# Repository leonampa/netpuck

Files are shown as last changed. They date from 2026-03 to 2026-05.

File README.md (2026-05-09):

# **NetPuck 5G: A Specialized 5GHz Wireless & Network Auditor**

----------

# 🗃️ This project has been archived.
**9th May:** It’s been 30 days since my latest ticket to Support, and over five weeks since the last human feedback. At this point, the project has shifted from a fun hardware challenge into a lingering chore on my to-do list. The educational ROI has hit its limit - I’ve already learned what I came for: Fusion 360, KiCad, etc. Since the program has stalled on the administrative side, I’m officially archiving the NetPuck to clear my headspace for projects that actually move forward. 

----------

# **0\. Introduction**

The NetPuck 5G is a handheld device, purpose-built to connect the worlds of software-driven network diagnostics and hardware-focused wireless analysis.

Made on Hack Club Blueprint 🚩- [https://blueprint.hackclub.com/projects/13740](https://blueprint.hackclub.com/projects/13740)

## **0.1 Why did I build this?**

* **I needed a network auditing device.** As a beginner IT Support Technician, I have a vast variety of tools for every job, but I've been lacking tools (and knowledge) regarding networking infrastructure. I've been making do with my phone and generic, no-brand WiFi strength scanning applications on my phone, but that is just not reliable for my purpose.  
* **I wanted to learn about hardware engineering.** I've always been interested in the “guts” of the devices around me. From a very young age, with a screwdriver in hand, I started taking devices that would otherwise be trashed apart, curious to see what makes them work. A few months ago, I also bought a soldering iron, and learned the skill of soldering and desoldering. In my curious journey of hardware engineering, the next step would be designing and having a custom PCB made.  
* **I wanted something to showcase in my portfolio.** Projects and contributions are largely important factors in one's portfolio, especially at an age where they cannot work, like me. I wanted to enrich my portfolio with personal projects, and Hack Club’s blueprint was the perfect, guided opportunity for me to do so.

## **0.2 What is it made of?**

It uses:

* the Waveshare ESP32-S3 Pico, as the main processing unit for the entire device  
* a BW16, solely for Access Point scanning, thanks to its 5GHz capabilities   
* a W5500 Ethernet module, for listing details about the network it is connected to  
* a 1.8’ inch LCD module, for providing all information gathered from the aforementioned boards to the user  
* a low-profile 5-way digital navigation joystick, for navigating the menus of the device  
* a MH-CD42 charging and boost-up module and two Samsung 18650 batteries, for powering the device from batteries, reliably.

## **0.3 So, what does it do?**

The NetPuck 5G has two functions; Wireless Access Point strength scanning, and Wired Network details.

* Wireless Access Point strength scanning  
  * This function uses the BW16, which communicates with the ESP32 via UART to list all 2.4GHz and 5GHz Access Points within reach, and the strength of each one, measured in dBm.  
* LAN details  
  * This function detects specific details about the network the W5500 module is plugged into. Specifically: ICMP Echo to 8.8.8.8, Gateway IP (from DHCP Lease), ICMP Echo to Gateway (Confirms local LAN integrity), LLDP (Passive sniff for Link Layer Discovery Protocol packets), Reverse DNS lookup of the Gateway’s Public IP, Gateway Domain Name (from DHCP Option 15), NLA Information, Gateway MAC (ARP-resolved)

# **1\. Pinout**

Grounds not listed; all grounds connect to each other  
The Pin/As/To/For tables are read as: The Pin \[Pin\] functions as/is labeled as \[As\], and goes to pin \[To\], (and is used) for \[For\].   

## **1.1 ESP32-S3**

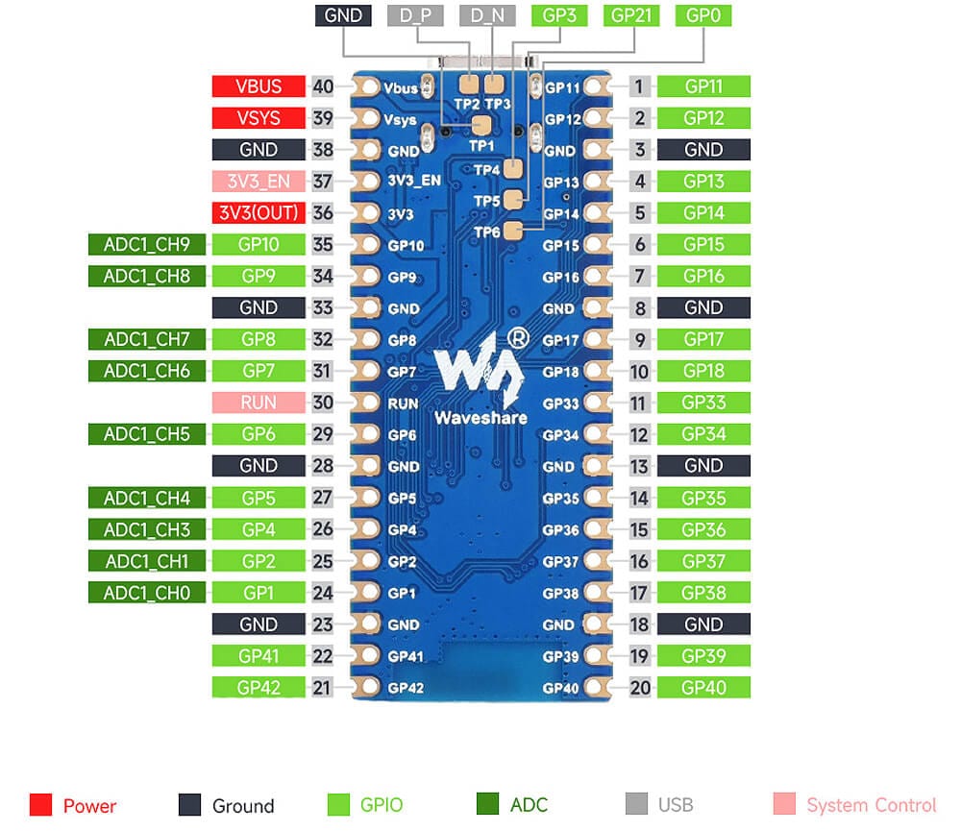
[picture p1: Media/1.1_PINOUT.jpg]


| Pin | As | To | For |
| :---- | :---- | :---- | :---- |
| Vbus/40 | \+5V | MH-CD42 @ 5V OUT | Powering the ESP |
| GP5/27 | LCD\_BL | LCD @ BL | Controlling the backlight |
| GP6/29 | W5500\_RST | W5500 @ RST | Resetting the W5500 |
| GP7/31 | LCD\_RST | LCD @ RST | LCD’s Resetting the LCD |
| GP8/32 | LCD\_DC | LCD @ DC | Data/Command |
| GP9/33 | W5500\_CS | W5500 @ CS | W5500’s SPI Chip Select  |
| GP10/34 | LCD\_CS | LCD @ CS | LCD’s SPI Chip Select |
| 3V3/36 | 3V3 | LCD @ VCC, W5500 @ V | Powering the LCD and W5500 |
| GP11/1 | SPI\_MOSI | LCD @ DIN, W5500 @ MO | Transferring data via SPI from the ESP32 (Master), to the LCD and W5500 (Slaves) |
| GP12/2 | SPI\_SCK | LCD @ CLK, W5500 @ SCK | Serial Clock for SPI |
| GP13/4 | SPI\_MISO | W5500 @ MI | Transferring data via SPI from the W5500 (Slave) to the ESP32 (Master) |
| GP14/5 | BW16\_EN | BW16 @ EN | BW16’s Enable Pin |
| GP17/9 | BW16\_RX | BW16 @ 7 | UART (ESP32 → BW16) |
| GP18/10 | BW16\_TX | BW16 @ 8 | UART (ESP32 ← BW16) |
| GP34/12 | MID | STICK @ MID | Joystick’s Click |
| GP35/14 | UP | STICK @ UP | Joystick’s Up |
| GP36/15 | DOWN | STICK @ DOWN | Joystick’s Down |
| GP37/16 | LEFT | STICK @ LEFT | Joystick’s Left |
| GP38/17 | RIGHT | STICK @ RIGHT | Joystick’s Right |

## **1.2 BW16**

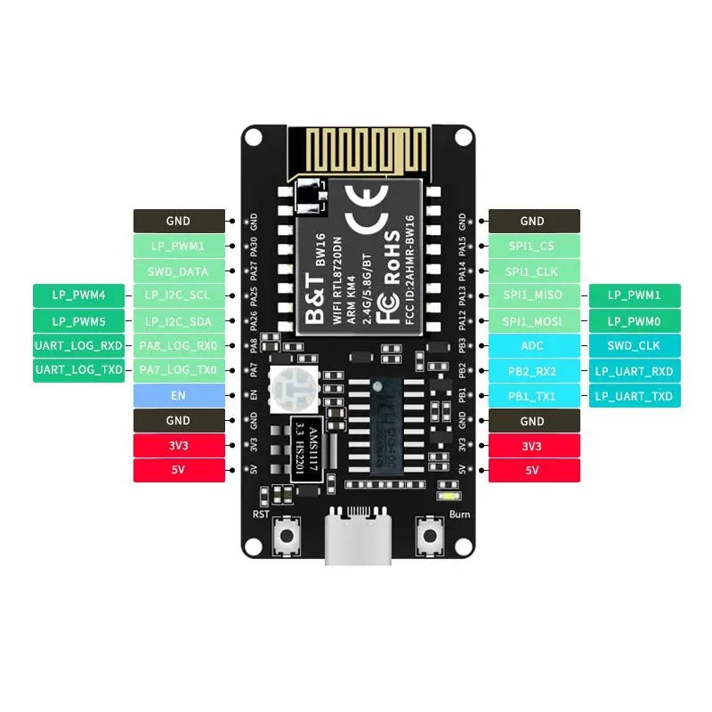
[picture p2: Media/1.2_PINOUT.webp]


| Pin | As | To | For |
| :---- | :---- | :---- | :---- |
| 5V | \+5V | MH-CD42 @ 5V OUT | Powering the BW16 |
| PA7/TX | BW16\_TX | ESP @ GP17/9 | UART (ESP32 ← BW16) |
| PA8/RX | BW16\_RX | ESP @ GP18/10 | UART (ESP32 → BW16) |
| EN | BW16\_EN | ESP @ GP14/5 | Enable Pin |

## **1.3 W5500**

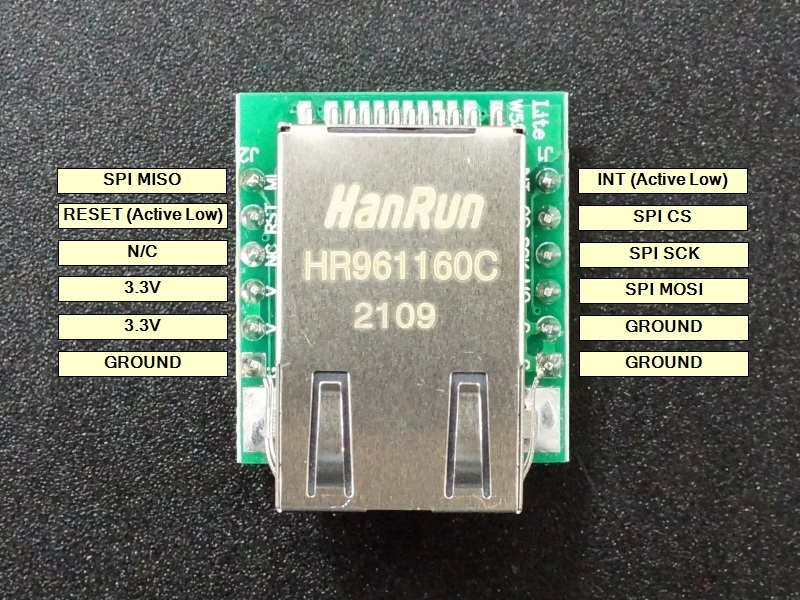
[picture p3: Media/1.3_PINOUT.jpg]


| Pin | As | To | For |
| :---- | :---- | :---- | :---- |
| RST | W5500\_RST | ESP @ GP6/29 | Resetting the W5500 |
| CS | W5500\_CS | ESP @ GP9/34 | W5500’s SPI Chip Select  |
| V | 3V3 | ESP @ 3V3 | Powering the LCD and W5500 |
| SCK | SPI\_SCK | ESP @ GP12/2 | Serial Clock for SPI |
| MI | SPI\_MISO | ESP @ GP13/4 | Transferring data via SPI from the W5500 (Slave) to the ESP32 (Master) |
| MO | SPI\_MOSI | ESP @ GP11/1 | Transferring data via SPI from the ESP32 (Master), to theW5500 (Slave) |

## **1.4 LCD**

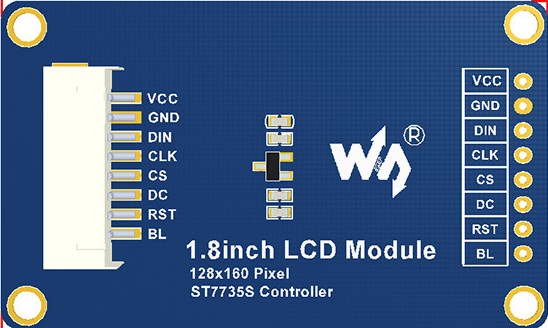
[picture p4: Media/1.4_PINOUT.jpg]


| Pin | As | To | For |
| :---- | :---- | :---- | :---- |
| BL  | LCD\_BL | ESP @ GP5/27 | Controlling the backlight |
| RST  | LCD\_RST | ESP @ GP7/31 | Resetting the LCD |
| DC  | LCD\_DC | ESP @ GP8/32 | LCD’s Data/Command |
| CS  | LCD\_CS | ESP @ GP10/34 | LCD’s SPI Chip Select |
| VCC  | 3V3 | ESP @ 3V3/36 | Powering the LCD |
| DIN  | SPI\_MOSI | ESP @ GP11/1 | Transferring data via SPI from the ESP32 (Master), to the LCD (Slave) |
| CLK  | SPI\_SCK | ESP @ GP12/2 | Serial Clock for SPI |

## **1.5 Joystick** 

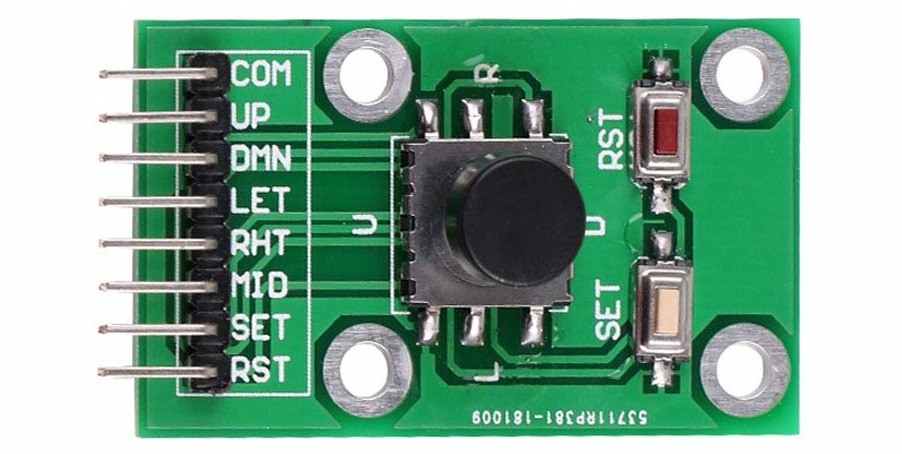
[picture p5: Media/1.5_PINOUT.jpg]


| Pin | As | To | For |
| :---- | :---- | :---- | :---- |
| MID | MID | ESP @ GP34/12 | Joystick’s Click |
| UP | UP | ESP @ GP35/14 | Joystick’s Up |
| DOWN | DOWN | ESP @ GP36/15 | Joystick’s Down |
| LEFT | LEFT | ESP @ GP37/16 | Joystick’s Left |
| RIGHT | RIGHT | ESP @ GP38/17 | Joystick’s Right |

## **1.6 MH-CD42 Charging Module**

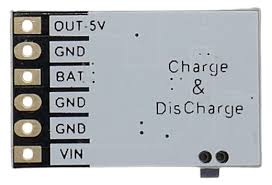
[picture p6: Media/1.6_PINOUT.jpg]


| Pin | As | To | For |
| :---- | :---- | :---- | :---- |
| 5V OUT | \+5V | ESP @ Vbus/40, BW16 @ 5V | Powering the ESP and BW16 |
| VIN  | VUSB | USB @ V | Powering the MH-CD42 |
| BAT | VBAT | (external batteries) | Powering the MH-CD42 |

## **1.7 USB Port**

| Pin | As | To | For |
| :---- | :---- | :---- | :---- |
| V | VUSB | VIN | Powering the MH-CD42 |

# **2\. PCB**

I used KiCad to design the PCB. Through a few struggles (as described on Journal), I landed on this design:

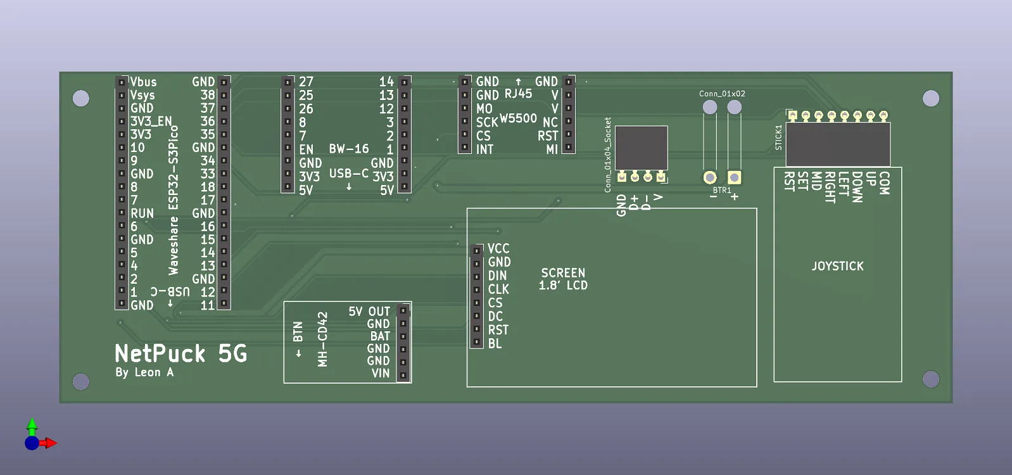
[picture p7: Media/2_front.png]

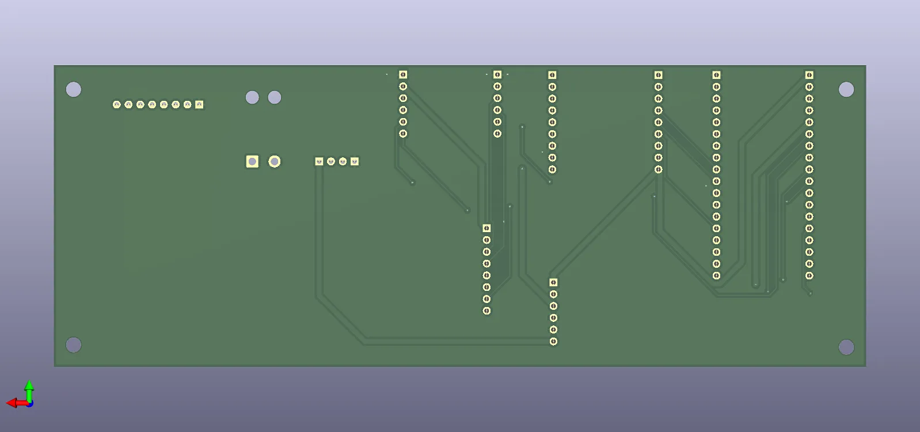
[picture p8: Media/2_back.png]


# **3\. Case**

I used Autodesk Fusion to make the case (as described on Journal). The enclosure is designed for field durability, featuring a 'Sandwich Mount' architecture. It utilizes M3 heat-set inserts and M3 Nylon screws, instead of Stainless Steel, to avoid signal interference.

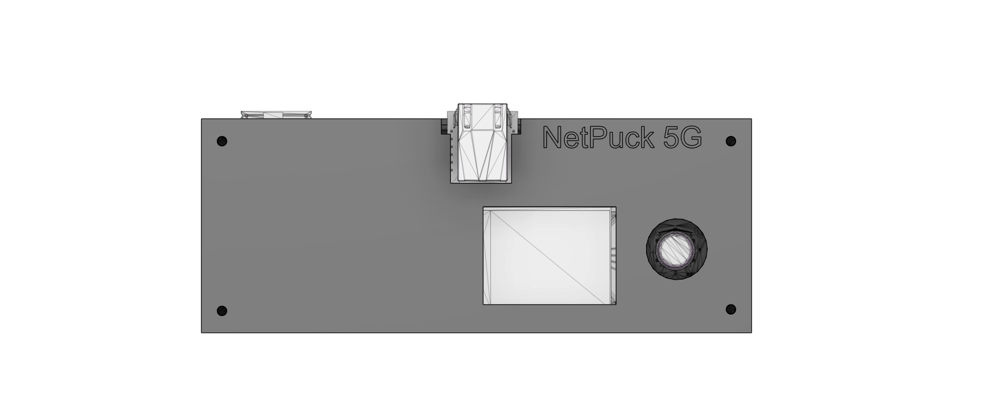
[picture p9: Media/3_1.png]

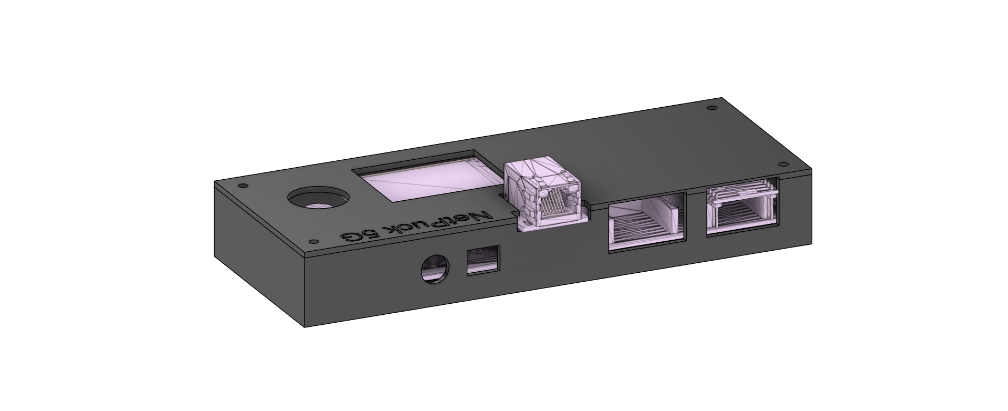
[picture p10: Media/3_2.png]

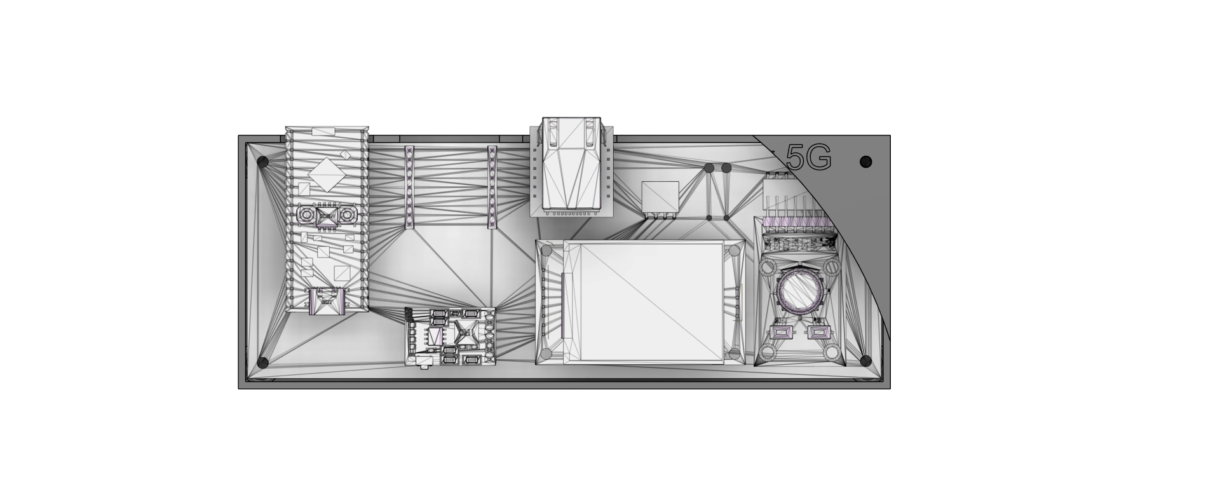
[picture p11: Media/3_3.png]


# **4\. Bill Of Materials**

| Item | €/pcs | Qty | € Total | Link |
| :---- | ----- | ----- | ----- | :---- |
| **GRobotronics** |  |  |  |  |
| eSUN PETG+HS 1.75mm 1kg \- Solid Black | €19.90 | 1 | €19.90 | [https://grobotronics.com/esun-petghs-1-75mm-1kg-solid-black.html](https://grobotronics.com/esun-petghs-1-75mm-1kg-solid-black.html) |
| Soldering Wire Brofil 60 100g 1mm | €7.20 | 1 | €7.20 | [https://grobotronics.com/soldering-wire-brofil-60-100g-1mm.html](https://grobotronics.com/soldering-wire-brofil-60-100g-1mm.html) |
| Waveshare ESP32-S3 Pico With Pre-soldered Headers | €13.60 | 1 | €13.60 | [https://grobotronics.com/waveshare-esp32-s3-development-board.html?variation\_id=18355](https://grobotronics.com/waveshare-esp32-s3-development-board.html?variation_id=18355) |
| Battery Lithium 18650 3.6V 3400mAh \- Samsung INR18650-35E | €5.80 | 2 | €11.60 | [https://grobotronics.com/battery-lithium-18650-3.6v-3400mah-8a-samsung-inr18650-35e.html](https://grobotronics.com/battery-lithium-18650-3.6v-3400mah-8a-samsung-inr18650-35e.html) |
| Battery Holder 2x18650 \- with Wires & Switch | €1.20 | 1 | €1.20 | [https://grobotronics.com/battery-lithium-18650-3.6v-3400mah-8a-samsung-inr18650-35e.html](https://grobotronics.com/battery-lithium-18650-3.6v-3400mah-8a-samsung-inr18650-35e.html) |
| Joystick Module 5-Way | €2.60 | 1 | €2.60 | [https://grobotronics.com/5-way-joystick-module.html](https://grobotronics.com/5-way-joystick-module.html) |
| Waveshare LCD 1.8" 128×160 SPI | €11.20 | 1 | €11.20 | [https://grobotronics.com/display-1.8-128x160-lcd-module.html](https://grobotronics.com/display-1.8-128x160-lcd-module.html) |
| USB Type-C Breakout Board \- Straight Header | €0.80 | 1 | €0.80 | [https://grobotronics.com/usb-type-c-breakout-board-straight-header.html](https://grobotronics.com/usb-type-c-breakout-board-straight-header.html) |
| Pin Header 1x40 Male 2.54 mm Black | €0.10 | 1 | €0.10 | [https://grobotronics.com/pin-header-1x40-male-2.54-mm-black.html](https://grobotronics.com/pin-header-1x40-male-2.54-mm-black.html) |
| Pin Header 1x10 Female 2.54mm | €0.17 | 4 | €0.68 | [https://grobotronics.com/pin-header-1x10-female-2.54mm.html](https://grobotronics.com/pin-header-1x10-female-2.54mm.html) |
| Pin Header 1x8 Female 2.54mm | €0.10 | 3 | €0.30 | [https://grobotronics.com/pin-header-1x8-female-2.54mm.html](https://grobotronics.com/pin-header-1x8-female-2.54mm.html) |
| Arduino Long Header 8pins | €0.25 | 1 | €0.25 | [https://grobotronics.com/arduino-long-header-8pins.html](https://grobotronics.com/arduino-long-header-8pins.html) |
| Pin Header Female 1x6 2.54mm | €0.08 | 3 | €0.24 | [https://grobotronics.com/pin-header-1x6-female-2.54mm.html](https://grobotronics.com/pin-header-1x6-female-2.54mm.html) |
| Pin Header 1x4 Long Stackable | €0.20 | 1 | €0.20 | [https://grobotronics.com/pin-header-1x4-long-stackable.html](https://grobotronics.com/pin-header-1x4-long-stackable.html) |
| Threaded Insert M3 \- 5.7x4.6mm | €0.15 | 10 | €1.50 | [https://grobotronics.com/threaded-insert-m3-short-3x4-6.html](https://grobotronics.com/threaded-insert-m3-short-3x4-6.html) |
| Bolt M3 \- Nylon (20mm) | €0.30 | 10 | €3.00 | [https://grobotronics.com/m3.html?variation\_id=12363](https://grobotronics.com/m3.html?variation_id=12363) |
| High Temperature Adhesive Tape 50mm \- 33m | €7.90 | 1 | €7.90 | [https://grobotronics.com/high-temperature-adhesive-tape-50mm-33m.html](https://grobotronics.com/high-temperature-adhesive-tape-50mm-33m.html) |
| YATO YT-2081 Side Cutting Pliers 115mm | €3.60 | 1 | €3.60 | [https://grobotronics.com/yato-cutting-pliers-115mm.html](https://grobotronics.com/yato-cutting-pliers-115mm.html) |
| Shipping (BOXNOW) | €0.00 | 0 | €0.00 |  |
| **Subtotal** |  | 44 | €85.87 |  |
|  |  |  |  |  |
| **AliExpress** |  |  |  |  |
| Dual-band WiFi \+ Bluetooth 5.0 IoT Core Board (BW16 RTL8720DN) Suitable for Arduino and Smart Home Projects (IPEX Antenna) | €7.24 | 1 | €9.52 | [https://www.aliexpress.com/item/1005010064459718.html?spm=a2g0o.detail.0.0.7236U0QJU0QJSg\&mp=1\&pdp\_npi=6%40dis%21EUR%21EUR%209.55%21EUR%201.95%21%21EUR%201.95%21%21%21%402103835e17741877141951141e5be7%2112000051007214201%21ct%21GR%21-1%21%211%210%21](https://www.aliexpress.com/item/1005010064459718.html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) |
| 1PCS W5500 Module TCP/IP Ethernet Module Compatible with WIZ820io Network Interface RC5 IoT for Arduino | €3.91 | 1 | €4.54 | [https://www.aliexpress.com/item/1005004679288698.html?spm=a2g0o.detail.0.0.7236U0QJU0QJSg\&mp=1\&pdp\_npi=6%40dis%21EUR%21EUR%204.54%21EUR%200.88%21%21EUR%200.88%21%21%21%402103835e17741877141951141e5be7%2112000030074096066%21ct%21GR%21-1%21%211%210%21](https://www.aliexpress.com/item/1005004679288698.html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) |
| 5/10pcs DC 5V 2A Mobile Power Diy Board 4.2V Charge/Discharge(boost)/battery protection/indicator module 3.7V lithium 18650 (MH-CD42) | €2.71 | 1 | €3.13 | [https://www.aliexpress.com/item/1005007432099008.html?spm=a2g0o.productlist.main.1.6d655d0d201MlN\&algo\_pvid=0b38d990-1f78-4ed4-ab89-ce53223c6fe6\&algo\_exp\_id=0b38d990-1f78-4ed4-ab89-ce53223c6fe6-8\&pdp\_ext\_f=%7B%22order%22%3A%22861%22%2C%22eval%22%3A%221%22%2C%22fromPage%22%3A%22search%22%7D\&pdp\_npi=6%40dis%21EUR%213.13%212.71%21%21%213.53%213.06%21%4021039a5b17741899750876391e3fa0%2112000040730748938%21sea%21GR%216308147579%21X%211%210%21n\_tag%3A-29919%3Bd%3A73d1907e%3Bm03\_new\_user%3A-29895%3BpisId%3A5000000202472607\&curPageLogUid=w2UUTZk6Qdsr\&utparam-url=scene%3Asearch%7Cquery\_from%3A%7Cx\_object\_id%3A1005007432099008%7C\_p\_origin\_prod%3A](https://www.aliexpress.com/item/1005007432099008.html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) |
| Shipping (AliExpress Choice) | €0.00 | 0 | €0.00 |  |
| **Subtotal** |  | 3 | €17.19 |  |
|  |  |  |  |  |
| **JLCPCB** |  |  |  |  |
| PCB (2 layers) | €7.43 | 1 | €7.43 |  |
| Shipping (Global Standard Direct Line) | €7.75 | 1 | €7.75 |  |
| New User Discount | \-€5.19 | 1 | \-€5.19 |  |
|  |  |  | €9.99 |  |
|  |  |  |  |  |
| **TOTAL** |  |  | €113.05 |  |
| **Conversion to USD (rate from Google Finance, €1 \=** | $1.154 |  | $130.49 |  |

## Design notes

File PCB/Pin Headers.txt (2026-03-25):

Pin Headers
ESP32: 2*10pF, 2*8pF
BW16: 2*10pF
MH-CD42: 1*6pF, 1*6pM
W5500: 2*6pF
Screen: 1*8pF, 1*8pM
USB: 1*4pFAR
Joystick: 1*8pFAL

Total
4*10pF
3*8pF, 1*8pM, 1*8pFAL
3*6pF, 1*6pM
1*4pFAR
=14

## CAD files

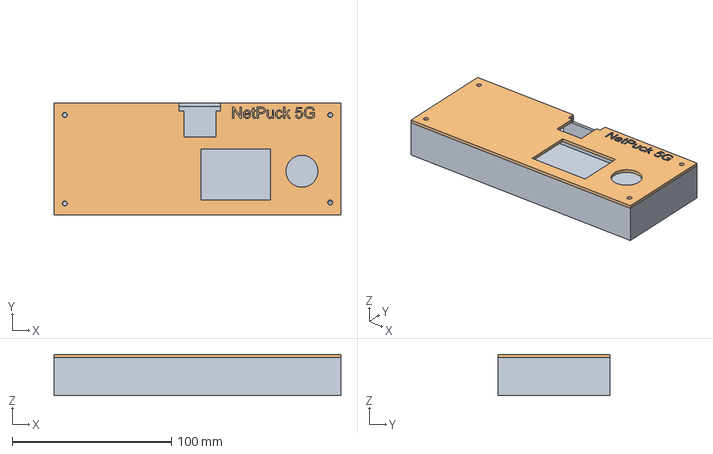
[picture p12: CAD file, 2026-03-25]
Case/NetPuck5G (case without PCB).step
180.0 x 70.0 x 26.0 mm

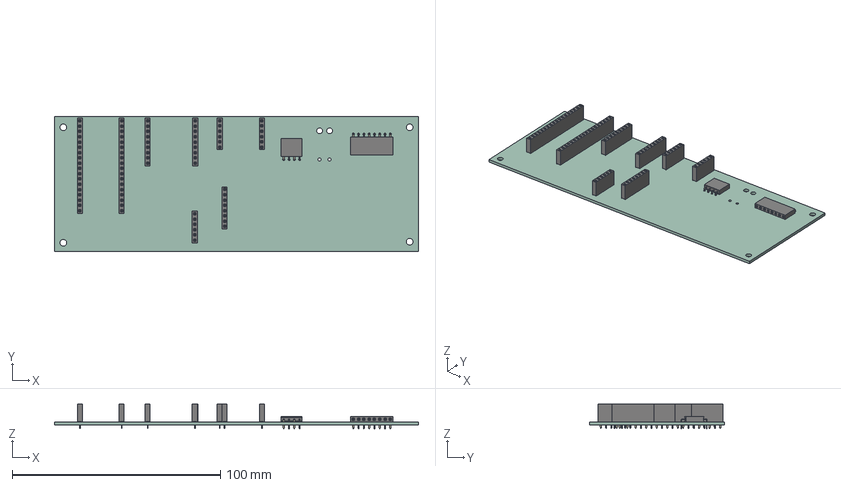
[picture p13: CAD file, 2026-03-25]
PCB/NetPuck5G.step
175.0 x 65.0 x 11.8 mm
PinSocket_1x06_P2.54mm_Vertical x 3
PinSocket_1x09_P2.54mm_Vertical x 2
PinSocket_1x18_P2.54mm_Vertical x 2
PinSocket_1x08_P2.54mm_Horizontal
PinSocket_1x08_P2.54mm_Vertical
PinSocket_1x04_P2.54mm_Horizontal
NetPuck5G_PCB

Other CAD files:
Case/NetPuck5G (case with PCB).step
Case/NetPuck5G (case with PCB).f3d
Case/NetPuck5G (case without PCB).f3d

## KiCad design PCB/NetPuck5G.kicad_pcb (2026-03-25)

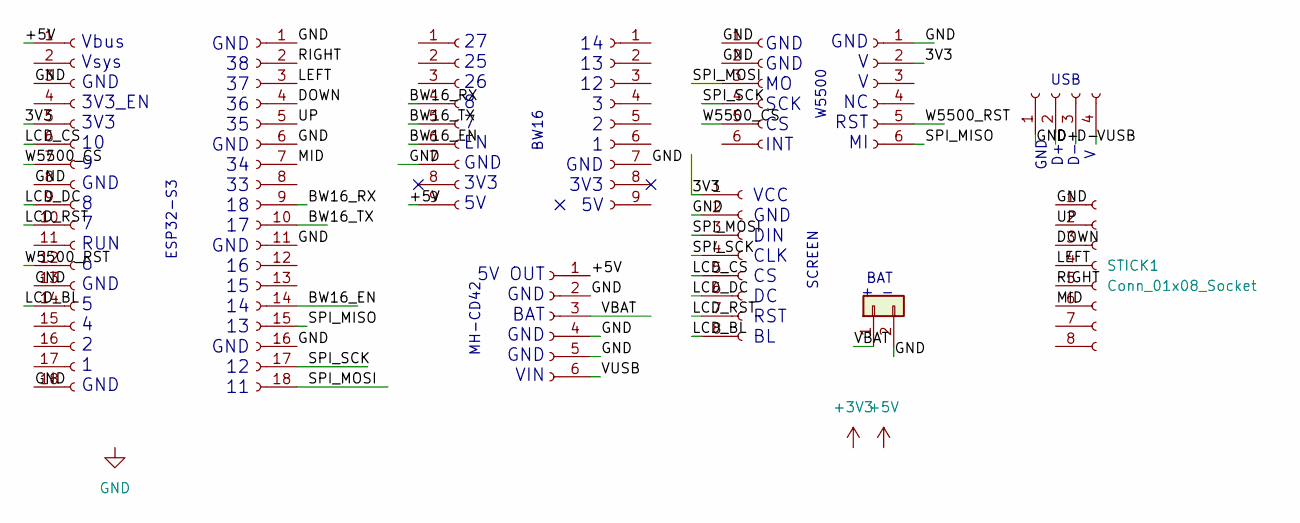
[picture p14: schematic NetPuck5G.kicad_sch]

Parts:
BTR1: Conn_01x02
BW-16_L1, BW-16_R1: Conn_01x09_Socket
ESP_L1: ESP_L
ESP_R1: Conn_01x18_Socket
ETH_L1: Conn_01x06_Socket
ETH_R1: Conn_01x06_Socket
MH-CD42: Conn_01x06_Socket
SCR1: Conn_01x08_Socket
STICK1: Conn_01x08_Socket
USB1: Conn_01x04_Socket

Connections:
+5V: BW-16_L1.9, ESP_L1.1, MH-CD42.1
/3V3: ESP_L1.5, ETH_R1.2, SCR1.1
/BW16_EN: BW-16_L1.6, ESP_R1.14
/BW16_RX: BW-16_L1.4, ESP_R1.9
/BW16_TX: BW-16_L1.5, ESP_R1.10
/D+: USB1.2
/D-: USB1.3
/DOWN: ESP_R1.4, STICK1.3
/LCD_BL: ESP_L1.14, SCR1.8
/LCD_CS: ESP_L1.6, SCR1.5
/LCD_DC: ESP_L1.9, SCR1.6
/LCD_RST: ESP_L1.10, SCR1.7
/LEFT: ESP_R1.3, STICK1.4
/MID: ESP_R1.7, STICK1.6
/RIGHT: ESP_R1.2, STICK1.5
/SPI_MISO: ESP_R1.15, ETH_R1.6
/SPI_MOSI: ESP_R1.18, ETH_L1.3, SCR1.3
/SPI_SCK: ESP_R1.17, ETH_L1.4, SCR1.4
/UP: ESP_R1.5, STICK1.2
/VBAT: BTR1.1, MH-CD42.3
/VUSB: MH-CD42.6, USB1.4
/W5500_CS: ESP_L1.7, ETH_L1.5
/W5500_RST: ESP_L1.12, ETH_R1.5
GND: BTR1.2, BW-16_L1.7, BW-16_R1.7, ESP_L1.3, ESP_L1.8, ESP_L1.13, ESP_L1.18, ESP_R1.1, ESP_R1.6, ESP_R1.11, ESP_R1.16, ETH_L1.1, ETH_L1.2, ETH_R1.1, MH-CD42.2, MH-CD42.4, MH-CD42.5, SCR1.2, STICK1.1, USB1.1

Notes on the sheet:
BAT
GND 38 37 36 35 GND 34 33 18 17 GND 16 15 14 13 GND 12 11
GND V V NC RST MI
14 13 12 3 2 1 GND 3V3 5V
Vbus Vsys GND 3V3_EN 3V3 10 9 GND 8 7 RUN 6 GND 5 4 2 1 GND
5V OUT GND BAT GND GND VIN
GND D+ D- V
USB
VCC GND DIN CLK CS DC RST BL
GND GND MO SCK CS INT
+ -
MH-CD42
W5500
SCREEN
27 25 26 8 7 EN GND 3V3 5V
ESP32-S3
BW16

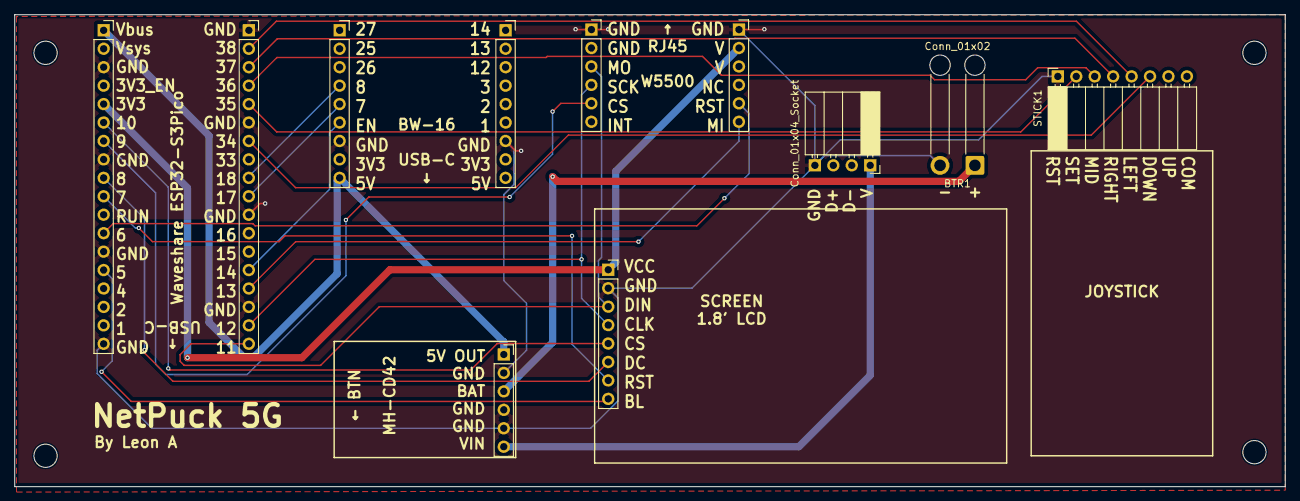
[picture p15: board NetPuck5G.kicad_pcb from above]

Board: 2 copper layers, 175.0 x 65.0 mm, 14 parts (0 on the bottom side), 22 nets.

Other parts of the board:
BotLeft: MountingHole_3.2mm_M3
BotRight: MountingHole_3.2mm_M3
TopLeft: MountingHole_3.2mm_M3

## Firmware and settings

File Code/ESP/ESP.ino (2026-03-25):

/* NetPuck 5G - Core Firmware (ESP32-S3) */

#include <SPI.h>
#include <Adafruit_GFX.h>
#include <Adafruit_ST7735.h>

// --- DISPLAY PINS (ST7735) ---
#define TFT_MOSI  11  // GP11
#define TFT_SCLK  12  // GP12
#define TFT_CS    10  // GP10
#define TFT_DC     8  // GP8
#define TFT_RST    7  // GP7
#define TFT_BL     5  // GP5 (Backlight Control)

// --- W5500 ETHERNET PINS ---
#define W5500_CS   9  // GP9
#define W5500_RST  6  // GP6
#define SPI_MISO  13  // GP13

// --- DIGITAL JOYSTICK PINS ---
#define JOY_MID   34  // GP34
#define JOY_UP    35  // GP35
#define JOY_DOWN  36  // GP36
#define JOY_LEFT  37  // GP37
#define JOY_RIGHT 38  // GP38

// --- BW16 5GHz MODULE PINS ---
#define BW16_EN   14  // GP14
#define BW16_RX   17  // GP17 (ESP32 TX -> BW16 RX)
#define BW16_TX   18  // GP18 (ESP32 RX <- BW16 TX)

// --- UI SETTINGS ---
#define COLOR_BG      0x0000 
#define COLOR_TEXT    0xFFFF 
#define COLOR_ACCENT  0x07E0 

Adafruit_ST7735 tft = Adafruit_ST7735(TFT_CS, TFT_DC, TFT_MOSI, TFT_SCLK, TFT_RST);

// --- APP STATES ---
enum State { MENU, SCANNING, RESULTS };
State currentState = MENU;

// --- MENU VARIABLES ---
int currentIdx = 0;
const int MAX_ITEMS = 4;
String menuItems[MAX_ITEMS] = {"5GHz SCANNER", "ETHERNET DIAG", "PACKET SNIFFER", "SETTINGS"};
bool redraw = true;

// --- SCAN VARIABLES ---
String scanSSID[8];
String scanRSSI[8];
int netCount = 0;

void setup() {
  // 1. PIN MODES
  pinMode(TFT_BL, OUTPUT);
  digitalWrite(TFT_BL, HIGH); // Backlight ON

  pinMode(W5500_CS, OUTPUT);
  digitalWrite(W5500_CS, HIGH); // De-select W5500 (Crucial!)

  pinMode(BW16_EN, OUTPUT);
  digitalWrite(BW16_EN, HIGH); 

  // 2. JOYSTICK
  pinMode(JOY_UP, INPUT_PULLUP);
  pinMode(JOY_DOWN, INPUT_PULLUP);
  pinMode(JOY_LEFT, INPUT_PULLUP);
  pinMode(JOY_RIGHT, INPUT_PULLUP);
  pinMode(JOY_MID, INPUT_PULLUP);

  // 3. START DISPLAY
  tft.initR(INITR_BLACKTAB);
  tft.setRotation(1);
  tft.fillScreen(COLOR_BG);
  
  // 4. START UART
  Serial1.begin(115200, SERIAL_8N1, BW16_RX, BW16_TX); 
}

void loop() {
  if (currentState == MENU) {
    handleMenu();
  } else if (currentState == SCANNING) {
    handleScanning();
  } else if (currentState == RESULTS) {
    handleResults();
  }
}

// --- LOGIC FUNCTIONS ---

void handleMenu() {
  if (redraw) {
    drawMenu();
    redraw = false;
  }
  
  if (digitalRead(JOY_UP) == LOW) {
    currentIdx = (currentIdx <= 0) ? MAX_ITEMS - 1 : currentIdx - 1;
    redraw = true; delay(150);
  }
  if (digitalRead(JOY_DOWN) == LOW) {
    currentIdx = (currentIdx >= MAX_ITEMS - 1) ? 0 : currentIdx + 1;
    redraw = true; delay(150);
  }
  if (digitalRead(JOY_MID) == LOW || digitalRead(JOY_RIGHT) == LOW) {
    if (currentIdx == 0) {
      // Start the Scanner
      currentState = SCANNING;
      tft.fillScreen(COLOR_BG);
      tft.setCursor(10, 60);
      tft.setTextColor(COLOR_ACCENT);
      tft.print("COMMANDING BW16...");
      
      netCount = 0; // Reset network list
      Serial1.println("SCAN"); // Send command to BW16
      delay(200);
    }
  }
}

void handleScanning() {
  // Wait for the BW16 to reply over Serial
  if (Serial1.available()) {
    String line = Serial1.readStringUntil('\n');
    line.trim();

    if (line == "END_SCAN" || line == "NO_NETWORKS") {
      currentState = RESULTS; // Scan finished!
      drawResultsScreen();
    } 
    else if (line.indexOf('|') > 0 && netCount < 8) {
      // Parse the incoming "SSID|RSSI" string
      int split = line.indexOf('|');
      scanSSID[netCount] = line.substring(0, split);
      scanRSSI[netCount] = line.substring(split + 1);
      netCount++;
      
      // Update screen so the user knows it's working
      tft.fillRect(0, 80, 160, 10, COLOR_BG);
      tft.setCursor(10, 80);
      tft.setTextColor(COLOR_TEXT);
      tft.print("Found: " + scanSSID[netCount-1]);
    }
  }
}

void handleResults() {
  // Pressing LEFT goes back to the main menu
  if (digitalRead(JOY_LEFT) == LOW || digitalRead(JOY_MID) == LOW) {
    currentState = MENU;
    redraw = true;
    delay(200);
  }
}

// --- UI DRAWING FUNCTIONS ---

void drawMenu() {
  tft.fillScreen(COLOR_BG);
  tft.fillRect(0, 0, 160, 16, COLOR_ACCENT);
  tft.setTextColor(COLOR_BG);
  tft.setCursor(4, 4);
  tft.print("NETPUCK 5G | READY");

  for (int i = 0; i < MAX_ITEMS; i++) {
    int y = 30 + (i * 18);
    if (i == currentIdx) {
      tft.fillRect(0, y - 4, 160, 16, 0x18C3);
      tft.setTextColor(COLOR_ACCENT);
      tft.setCursor(5, y);
      tft.print("> " + menuItems[i]);
    } else {
      tft.setTextColor(COLOR_TEXT);
      tft.setCursor(15, y);
      tft.print(menuItems[i]);
    }
  }
}

void drawResultsScreen() {
  tft.fillScreen(COLOR_BG);
  tft.fillRect(0, 0, 160, 16, COLOR_ACCENT);
  tft.setTextColor(COLOR_BG);
  tft.setCursor(4, 4);
  tft.print("5GHz NETWORKS FOUND");

  tft.setTextColor(COLOR_TEXT);
  if (netCount == 0) {
    tft.setCursor(10, 40);
    tft.print("No networks found.");
  } else {
    for (int i = 0; i < netCount; i++) {
      int y = 25 + (i * 12);
      // Print SSID on left, RSSI (signal strength) on right
      tft.setCursor(2, y);
      tft.print(scanSSID[i].substring(0, 15)); // Trim long names
      tft.setCursor(120, y);
      tft.print(scanRSSI[i] + "dB");
    }
  }
  
  tft.setTextColor(0x18C3); // Dim grey
  tft.setCursor(2, 115);
  tft.print("< Press LEFT to exit");
}

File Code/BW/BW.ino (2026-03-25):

/*
 * BW16 5GHz Coprocessor Firmware
 * Role: UART Slave Scanner 
 */
#include <WiFi.h>

void setup() {
  // Serial uses PA7 (TX) and PA8 (RX) by default on BW16
  Serial.begin(115200);
  
  if (WiFi.status() == WL_NO_SHIELD) {
    Serial.println("WiFi_FAIL");
    while (true);
  }
  
  Serial.println("BW16_READY");
}

void loop() {
  if (Serial.available()) {
    String cmd = Serial.readStringUntil('\n');
    cmd.trim();
    
    if (cmd == "SCAN") {
      // Ameba scanNetworks returns the number of networks found
      int n = WiFi.scanNetworks();
      
      if (n <= 0) {
        Serial.println("NO_NETWORKS");
      } else {
        // Send up to 8 networks back to the ESP32
        int limit = (n > 8) ? 8 : n; 
        for (int i = 0; i < limit; ++i) {
          // Format: SSID|RSSI
          Serial.print(WiFi.SSID(i));
          Serial.print("|");
          Serial.println(WiFi.RSSI(i));
        }
      }
      Serial.println("END_SCAN");
    }
  }
}
